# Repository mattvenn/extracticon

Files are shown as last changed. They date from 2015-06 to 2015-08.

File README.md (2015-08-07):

# Extracticon!

* Turns on your extraction automatically when you use an attached tool,
* Cheap to build,
* 1 sided PCB easy to home fab,
* Rated at 1.8KW Max,
* Thermal cutout.

# Photos

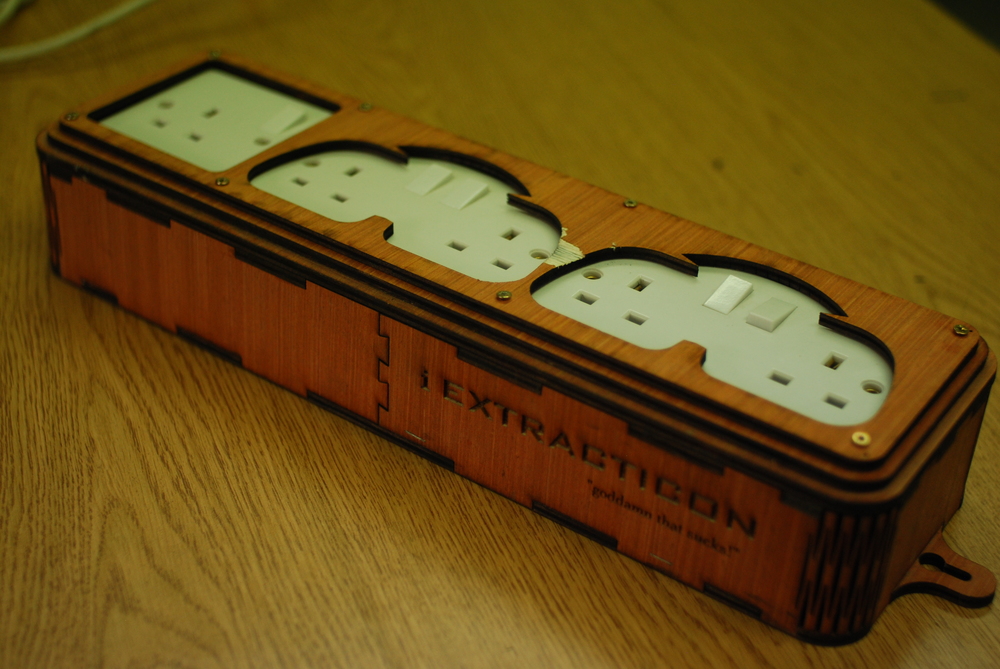
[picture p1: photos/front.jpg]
front


[More pics](photos/)

# Electronics

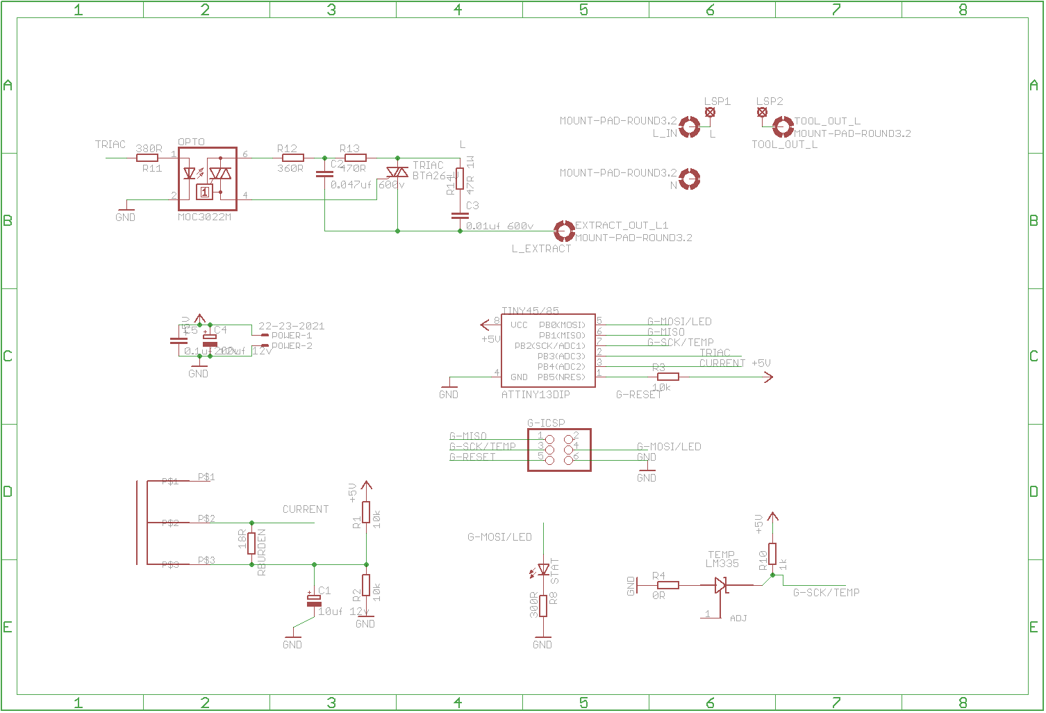
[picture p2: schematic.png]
schematic


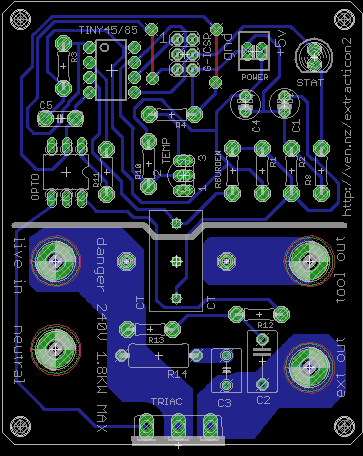
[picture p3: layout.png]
pcb layout


# Electronics BOM

[BOM](bom.txt)

* Parts missing from the BOM are standard resistors and LEDs. 
* Ensure caps are at least 6V, preferable 12V.

# Case

* [Case BOM & Build notes](build_notes.md)
* [DXF for laser cutting](case.dxf)

# Code

[Arduino code for ATTiny45](extracticon_tiny/)

# Testing

* Circuit board is rated for 1.8KW Max.
* Current capacity can be increased by adding solder to the traces.
* We tested 2KW for 30 minutes.

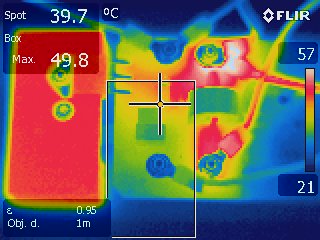
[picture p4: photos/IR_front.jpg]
front


This thermal picture shows maximum of 50C so internal thermal cutout set to 60C.

# References

* [This calculator](http://circuitcalculator.com/wordpress/2006/01/31/pcb-trace-width-calculator/) was used to calculate that with 5mm traces we can switch 7.7A or 1.8KW at 240VAC.
* [current sensing](http://openenergymonitor.org/emon/buildingblocks/ct-sensors-interface)
* [using tiny44/45 with arduino](http://highlowtech.org/?p=1695)

# License

This hardware is licensed under the [CERN open hardware license 1.2](http://www.ohwr.org/attachments/2388/cern_ohl_v_1_2.txt), which also included in this repository.

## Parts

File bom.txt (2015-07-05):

Mfg Part Num	Mfg Name	VID	Vendor Part Num	Description	Qty-1	Qty-5	Qty-25	Part References	Value
*** ERROR - PART '*' NOT FOUND FOR: "STAT"
75869-131LF	FCI	farnell	2293757	HEADER, 2x3 SPI HEADER, 2.54MM 	1	5	25	"G-ICSP"	
MKS2J021001H00KSSD	WIMA	farnell	1519308	CAP, FILM, PET, 10NF, 630V, RAD 	1	5	25	"C3"	0.01uf 600v
*** ERROR - PART '*' NOT FOUND FOR: "C5"
MKS4J024702F00KSSD	WIMA	farnell	1890169	CAP, FILM, PET, 47NF, 630V, RAD 	1	5	25	"C2"	0.047uf 600v
*** ERROR - PART '*' NOT FOUND FOR: "R4"
*** ERROR - PART '*' NOT FOUND FOR: "R10"
*** ERROR - PART '*' NOT FOUND FOR: "R1, R2, R3"
*** ERROR - PART '*' NOT FOUND FOR: "C1"
*** ERROR - PART '*' NOT FOUND FOR: "RBURDEN"
22-23-2021	MOLEX	farnell	1462926	HEADER, PIN, 2WAY 	1	5	25	"POWER"	22-23-2021
CFR100J47R	TE CONNECTIVITY	farnell	2329461	RESISTOR, CARBON , 47R, 1W, 5% 	1	5	25	"R14"	47R 1W
*** ERROR - PART '*' NOT FOUND FOR: "C4"
*** ERROR - PART '*' NOT FOUND FOR: "R8"
*** ERROR - PART '*' NOT FOUND FOR: "R12"
*** ERROR - PART '*' NOT FOUND FOR: "R11"
*** ERROR - PART '*' NOT FOUND FOR: "R13"
ATTINY45-20PU	ATMEL	farnell	1288352	MCU, 8BIT, ATTINY, 20MHZ, DIP-8 	1	5	25	"TINY13"	ATTINY13DIP
BTA26-600BRG	STMICROELECTRONICS	farnell	1057286	TRIAC, 25A, 600V, TOP-3 	1	5	25	"T1"	BTA26-V
56050C	MURATA	farnell	2291968	TRANSFORMER, 10A, 1:50, CURRENT 	1	5	25	"CT"	CT
LM335Z/NOPB	TEXAS INSTRUMENTS	farnell	1564652	IC, TEMP SENSOR, PRECISION, TO-92 	1	5	25	"U$2"	LM335
MOC3022-M	FAIRCHILD SEMICONDUCTOR	farnell	1021366	OPTOCOUPLER, TRIAC DRIVER 	1	5	25	"OK2"	MOC3022M
*** ERROR - PART '*' NOT FOUND FOR: "EXTRACT_OUT_L1, L_IN, N, TOOL_OUT_L"
*** ERROR - PART '*' NOT FOUND FOR: "LSP1, LSP2"

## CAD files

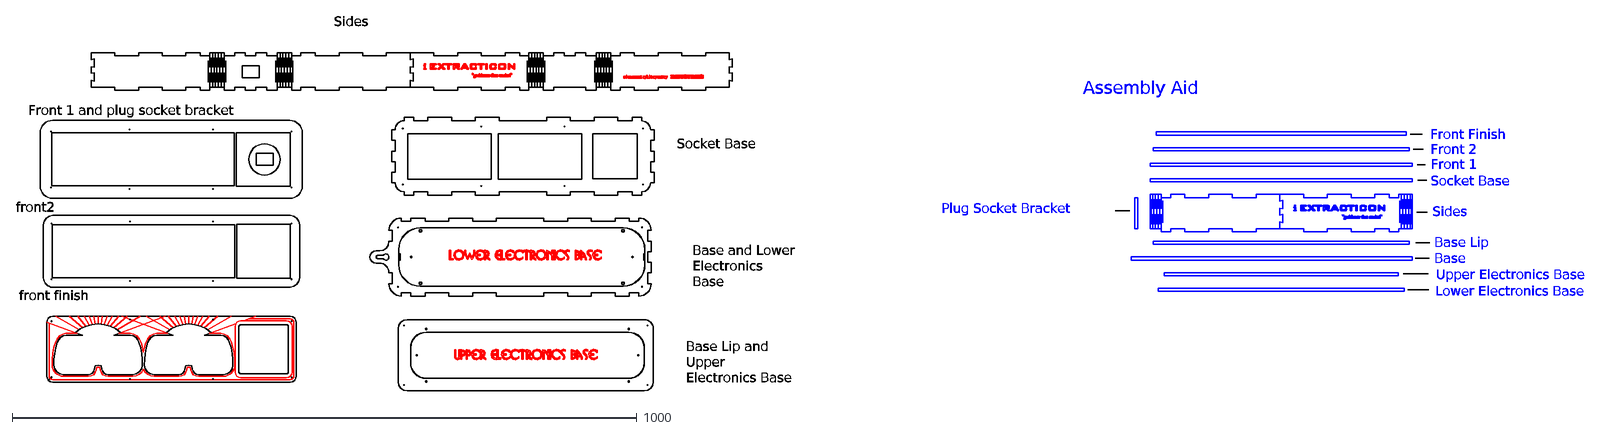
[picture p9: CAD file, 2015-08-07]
case.dxf
front2
front finish
Base Lip and
Upper
Electronics Base
Base and Lower
Electronics
Base
Front 1 and plug socket bracket
Base Lip
Front 1
Plug Socket Bracket
Socket Base
Sides
Front 2
Front Finish
Assembly Aid
Upper Electronics Base
Lower Electronics Base

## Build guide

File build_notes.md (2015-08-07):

# BOM

* [IEC plug](http://www.ebay.co.uk/itm/IEC-Male-Chassis-C14-Kettle-Socket-Plug-Connector-Power-Mains-Switch-DJ-UKC501-/151293063606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)
* double sockets x 2
* single socket x 1
* Kettle Lead
* 1.5 sheets of 800mm x 500mm 5mm ply
* Wood Glue
* 3mm x 12mm screws
* 20mm pins.
* 8mm staples and staple gun
* masking tape

# Construction info

* Laser cut the dxf out first. Make sure the red lines on the Front Finish and all the text is only etched!
* Wood glue the Lower and Upper Electronic Base together. Use a pin or a screw through the 2 aligning holes to get correct position. Use clamp or masking tape for good adhesion. Remove screws/pins when dry.
* Wood glue Base and Base Lip together. Use a pin or a screw through the aligning holes to get correct position. Use 6-10mm staples and a staple gun for  quicker assembly. Use staples in places you won't see them when finished (i.e. on the inside of the extracticon). Remove screws/pins.
* Countersink the 4 larger holes in Lower Electronics Base. Screw the completed Electronics Base to the Base Lip.
* Glue the castellations between Sides into the Base together. Adhesion can be aided by sanding or scraping of any blackened charred wood between joints to be glued. Use 6-10mm staples and a staple gun for  quicker assembly. Use staples in places you won't see them when finished (i.e. on the base)
* Glue the castellations between Socket Base and Sides together. Adhesion can be aided by sanding or scraping of any blackened charred wood between joints to be glued. Use 6-10mm staples and a staple gun for  quicker assembly. Use staples in places you won't see them when finished (i.e. on the Socket Base)
* Place plug sockets on top of socket base. Glue Front 1, Front 2 and Front Finish onto Socket Base and around the plug sockets. Use pins through the aligning holes to get correct position.
* Glue the Plug Socket Bracket on to the Side. Masking tape to hold it in place.
* Unscrew the Electronics Base. Mount the electronics and wire her all up.
* Dust away amigos!

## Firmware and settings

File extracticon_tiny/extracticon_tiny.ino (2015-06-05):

#define LED 0 //pin 5
#define TEMP A1 //pin 7
#define CUR A2 //pin 3
#define TRIAC 3 //pin 2
#define TEMP_HIGH 60
#define ON_DELAY 1000

//just looked at the numbers and guessed - not in real units
#define thresh 10000

//turn off after 2 second
#define off_delay 2000


unsigned long time = 0;

void setup()
{
  pinMode(LED,OUTPUT);
  pinMode(TRIAC,OUTPUT);
  digitalWrite(TRIAC,LOW);
  digitalWrite(LED,HIGH);
  for( int i = 0; i < 4; i ++)
  {
      digitalWrite(LED,LOW);
      delay(100);
      digitalWrite(LED,HIGH);
      delay(100);
  }
  digitalWrite(LED,LOW);

}

void loop()
{
  int sample;
  int offset = 512;
  
  double accum = 0;
  for( int i =0; i< 250; i++)
  {
    sample = analogRead(CUR) - offset;
    accum = accum + sample * sample;
  }

  int rawvoltage= analogRead(TEMP);
  float celcius= (rawvoltage/1024.0) * 500 - 273.15;

  //safety temp
  if(celcius > TEMP_HIGH)
  {
     digitalWrite(TRIAC,LOW);
     digitalWrite(LED,LOW);
  }
  else
  {
      if(accum > thresh)
      {
         digitalWrite(LED,HIGH);
         //delay to avoid blowing fuses
         delay(ON_DELAY);
         digitalWrite(TRIAC,HIGH);
         time = millis();
      }
      else if(millis() > time + off_delay)
      {
        digitalWrite(LED,LOW);
        digitalWrite(TRIAC,LOW);
      }
  }
  delay(100);
}

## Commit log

2015-06-05 layout and schematic
2015-06-19 increased trace size slightly after calculation
    [extracticon v2.brd]
2015-06-19 trace width calc
2015-06-19 trace increase
    [extracticon v2.brd]
2015-07-01 part values
    [extracticon v2.brd, extracticon v2.sch]
2015-07-05 exported images
    [extracticon v2.brd, extracticon v2.sch]
2015-07-05 bom and todo
2015-08-07 added Nics case
    [case.dxf]
